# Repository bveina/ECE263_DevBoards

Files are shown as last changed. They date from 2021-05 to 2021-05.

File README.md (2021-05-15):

# ECE 263 Breakout Boards
There are three revisions of the ECE 263 breakout board. each is published in this repository.

each folder contains the Eagle files, a pdf of each schematic, a gerber folder,and two png renders of the board, top and bottom.

## [Version 1 - The White Board](./ECE263_breakout_V1)
## [Version 2 - The Green Board](./ECE263_breakout_V2)
## [Version 3 - The Red Board](./ECE263_breakout_V3)

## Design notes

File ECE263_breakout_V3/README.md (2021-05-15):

# ECE 263 Breakout Board Version 3
This repository is the public repo for the version one board for ECE263 "The Red Board"
It is targeted towards the Atmel Xplained Mini328pb not all features will be available if connected to an Arduino.
this repo contains the original board files, and renders of the Schematic and PCB (top and bottom) hosted here for easy reference.

## Building your own
Version three was designed to be assembed automatically by the ECE department Pick and place machine or assembled by hand (in a pinch). all passives are 0805.

|part| part Number|
|---|---|
|seven segment display |LTC-5723HR|
|RGB LED | ASMB-MTB0-0A3A2|
|Buzzer |	PKMCS0909E4000-R1|
| Button| EVP-BFAC1A000|
| transistors| MMBT2222A |

## Potentiometers
Three potentiometers are connected across the power rail with wipers connected to the Analog to Digital Converter (ADC) pins.
- 328p pins PORT: C0, C1, C2

## Buttons
Three Momentary buttons are hooked up the processor to pull the inputs to ground when pressed.
Pull up resistors are onboard so the internal pull ups of the 328p/328pb don't need be activated.
- 328p pins: PORTE 0,1,2

## Seven Segment Display
A socket is provided for a 4 digit seven segment display with Common Cathodes.

- Digit Enables:
 - PORTB 0,1,2,3
- Anodes (abcdefg.):
 - PORTD 0,1,2,3,4,5,6,7

## RGB led
A SMD Common Anode LED is included on the expansion board.
each Cathode is connected to a PWM capable Pin.
Color Cathodes (BGR):
- PORT B3,B1,D6
Anode:
- PORT C3

## Speaker
A SMD peizo speaker is enabled by bringing PE3 high then can be controlled by toggling PD2.
D2 is also the modulator output on the atmega328pb.

## IO Expansion Connector
3 external connections are provided on PE0,PB0,PE1.
these have external pullups making them useful for a thermistor or external buttons. they are also the processors Input Capture pins

## SPI Connector
A six pin connector is located under the seven segment display to allow the connection of a  [MAX7221 breakout](https://github.com/bveina/Max7221-Driver).
or any SPI device.
pinout:
1. MOSI0
2. MISO0
3. GND
4. VCC
5. SCK0
6. PB2 (SS0)

## I2C:registered: / TWI Expansion
a 4 pin two wire interface is broken out for connection to external devices
1. GND
2. VCC
3. SDA0/PC4
4. SCL0/PC5

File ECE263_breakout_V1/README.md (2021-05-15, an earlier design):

# ECE 263 Breakout Board Version 1
This repository is the public repo for the version one board for ECE160/263 "the White Board"
it contains the original board files, and renders of the Schematic and Pcb (top and bottom) hosted here for easy reference.

This board was originally designed to mate with a standard arduino uno. but will also work with and atmel Xplained mini 328p or pb

## Potentiometers
Three potentiometers are connected across the power rail with wipers connected to the Analog to Digital Converter (ADC) pins.
- Arduino pins: A0, A1, A2
- 328p pins PORT: C0, C1, C2

## Buttons
Three Momentary buttons are hooked up the processor to pull the inputs to ground when pressed.
Pull up resistors are onboard so the internal pull ups of the 328p/328pb don't need be activated.
- Arduino pins: A3, A4, A5
- 328p pins: PORT C3, C4, C5

## Seven Segment Display
A socket is provided for a 4 digit seven segment display with common Cathodes.
Jumpers 3,4,5 must be set to enable either the seven segment display or the RGB led. Only one can be used at a time.

- Digit Enables:
 - Arduino: Digital 8,9,10,11
 - 328p: PORTB 0,1,2,3
- Anodes (abcdefg.):
 - Arduino: Digital 0,1,2,3,4,5,6,7
 - 328p: PORTD 0,1,2,3,4,5,6,7

## RGB led
A 10MM RGB Common Anode LED is included on the expansion board but must be selected by moving jumpers 3,4,5.

Color Cathodes (BGR):
- Arduino: Digital 9,10,11
- 328p: PORTB 1,2,3
Anode:
- Arduino: Digital 12
- 328p: PORTB 4

## Speaker
A speaker is connected to Digital 13/ PORTB5.

The less this annoying buzzer is used, the better.
its constant buzzing is what led to a complete redesign of this board...

## Expansion Connector
3 external connections are provided on portC/analog pins 3,4,5.
these have external pullups making them useful for a thermistor or external buttons.

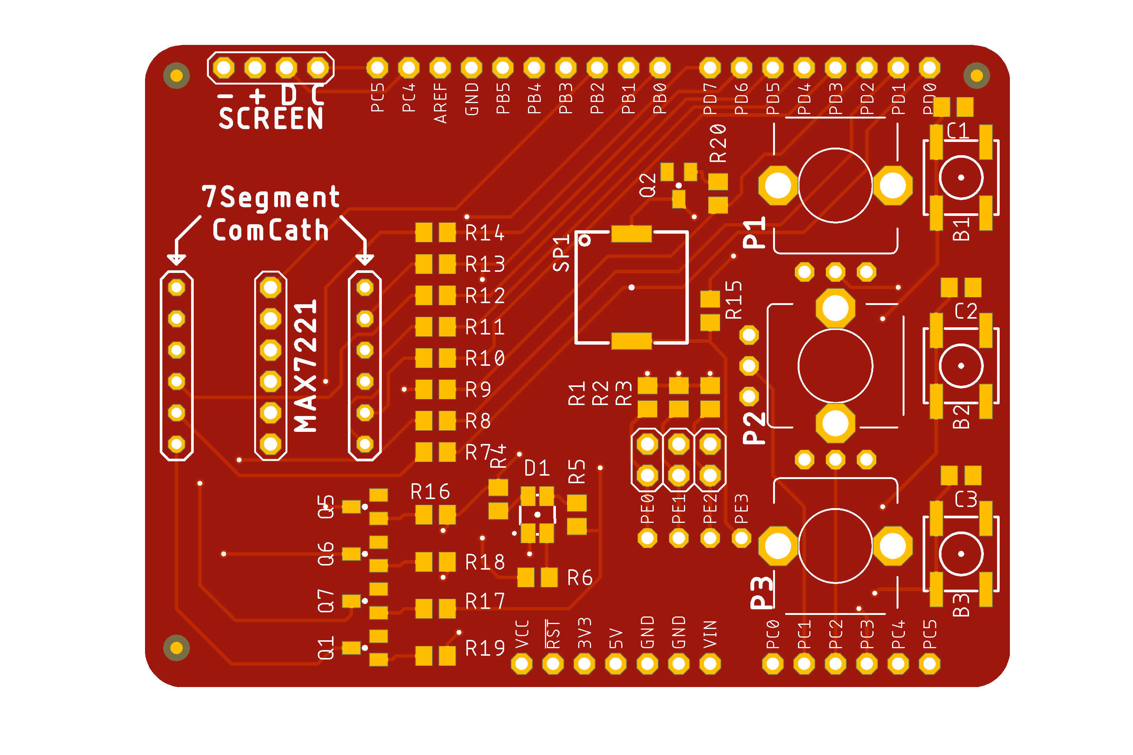
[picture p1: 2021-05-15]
ECE263_breakout_V3/ECE263_V3_PCB_Top.png

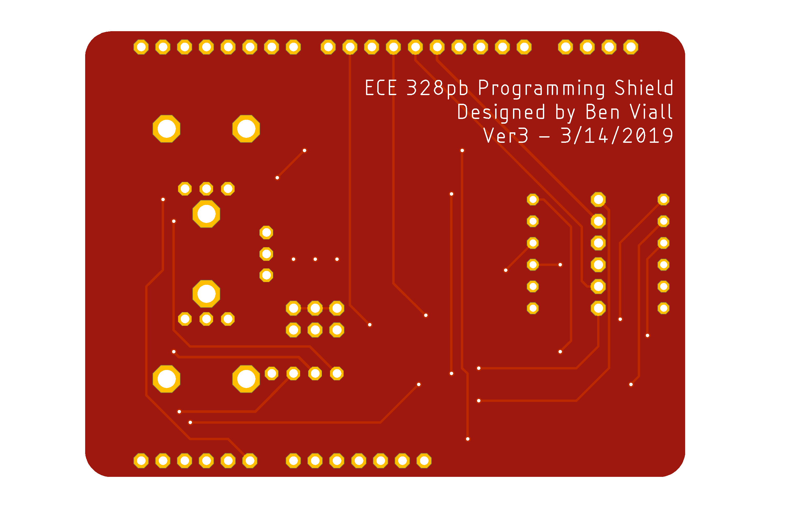
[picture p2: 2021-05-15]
ECE263_breakout_V3/ECE263_V3_Bot.png

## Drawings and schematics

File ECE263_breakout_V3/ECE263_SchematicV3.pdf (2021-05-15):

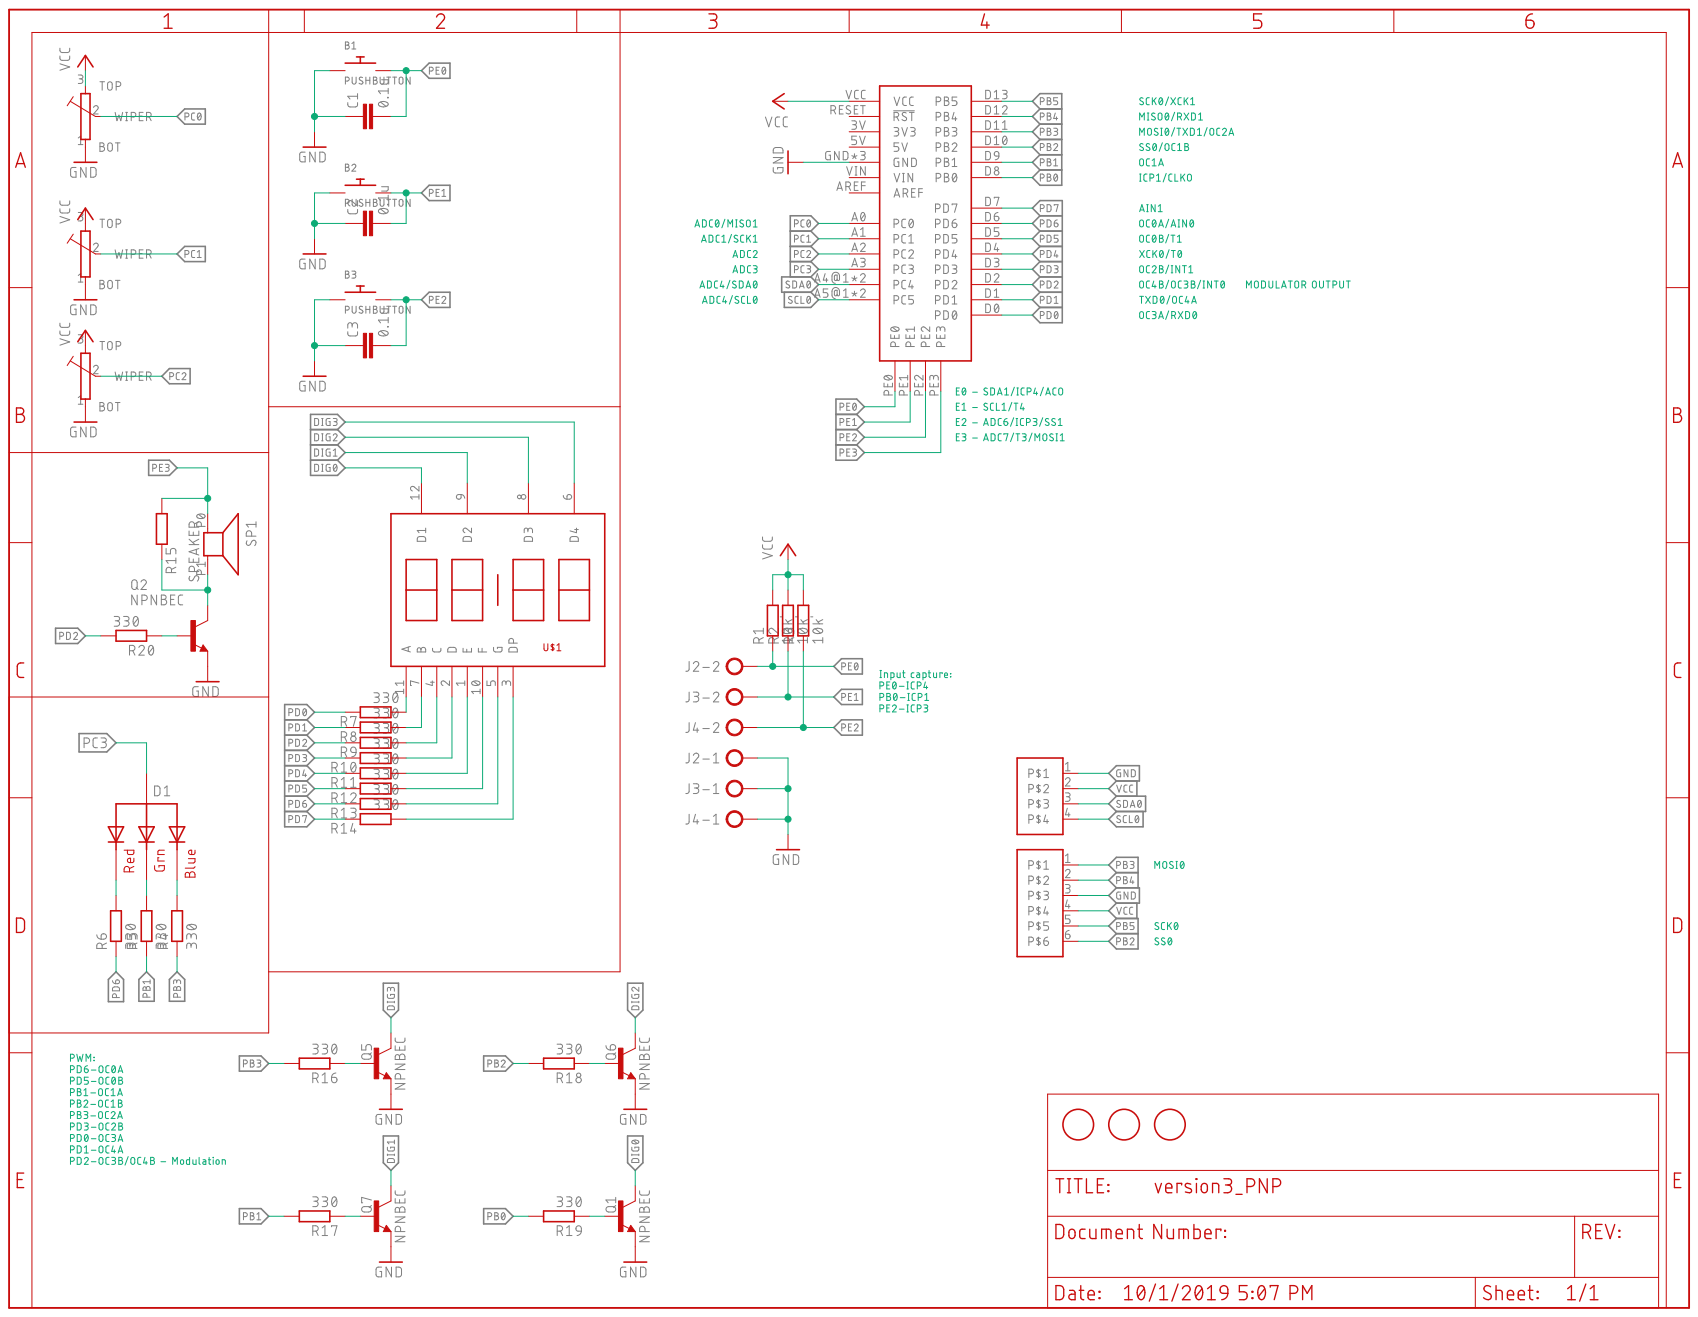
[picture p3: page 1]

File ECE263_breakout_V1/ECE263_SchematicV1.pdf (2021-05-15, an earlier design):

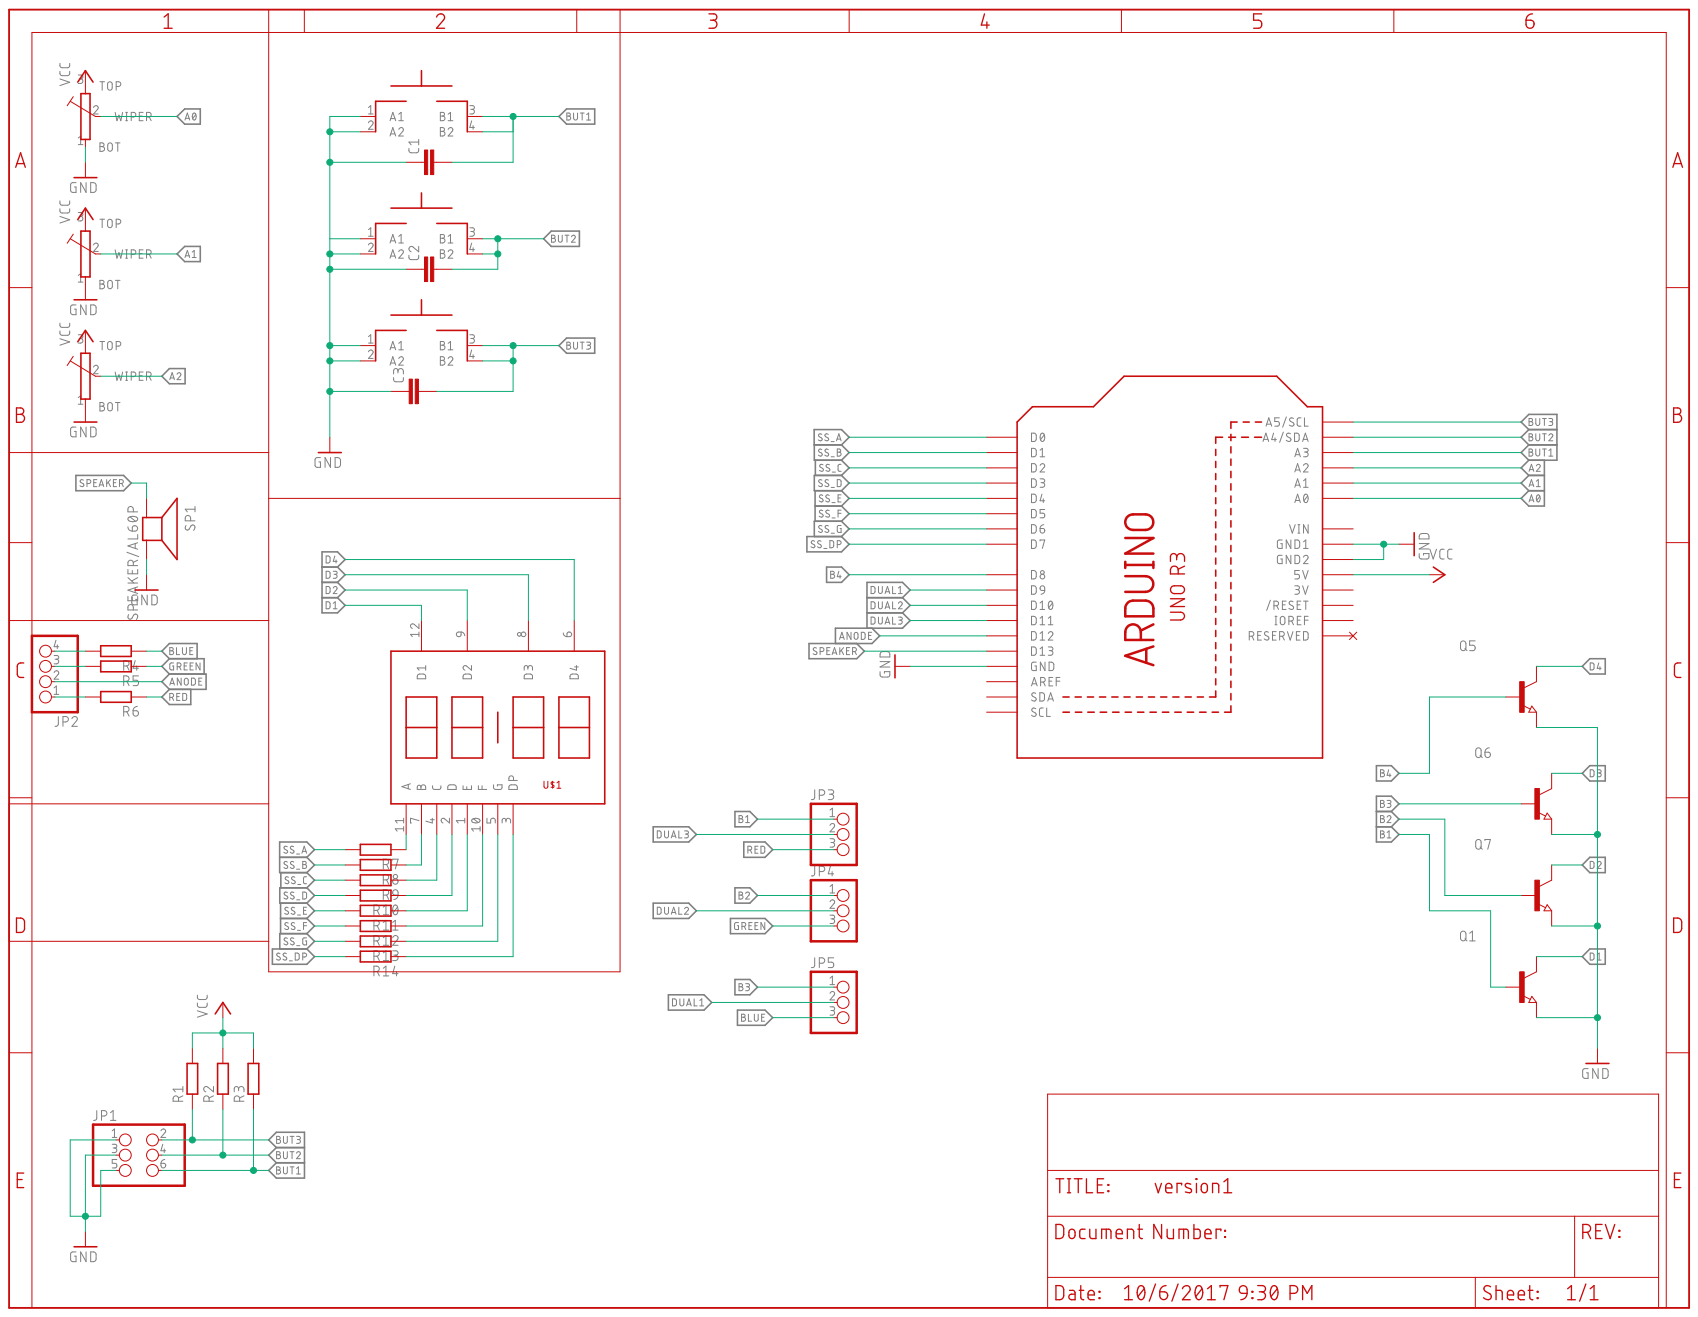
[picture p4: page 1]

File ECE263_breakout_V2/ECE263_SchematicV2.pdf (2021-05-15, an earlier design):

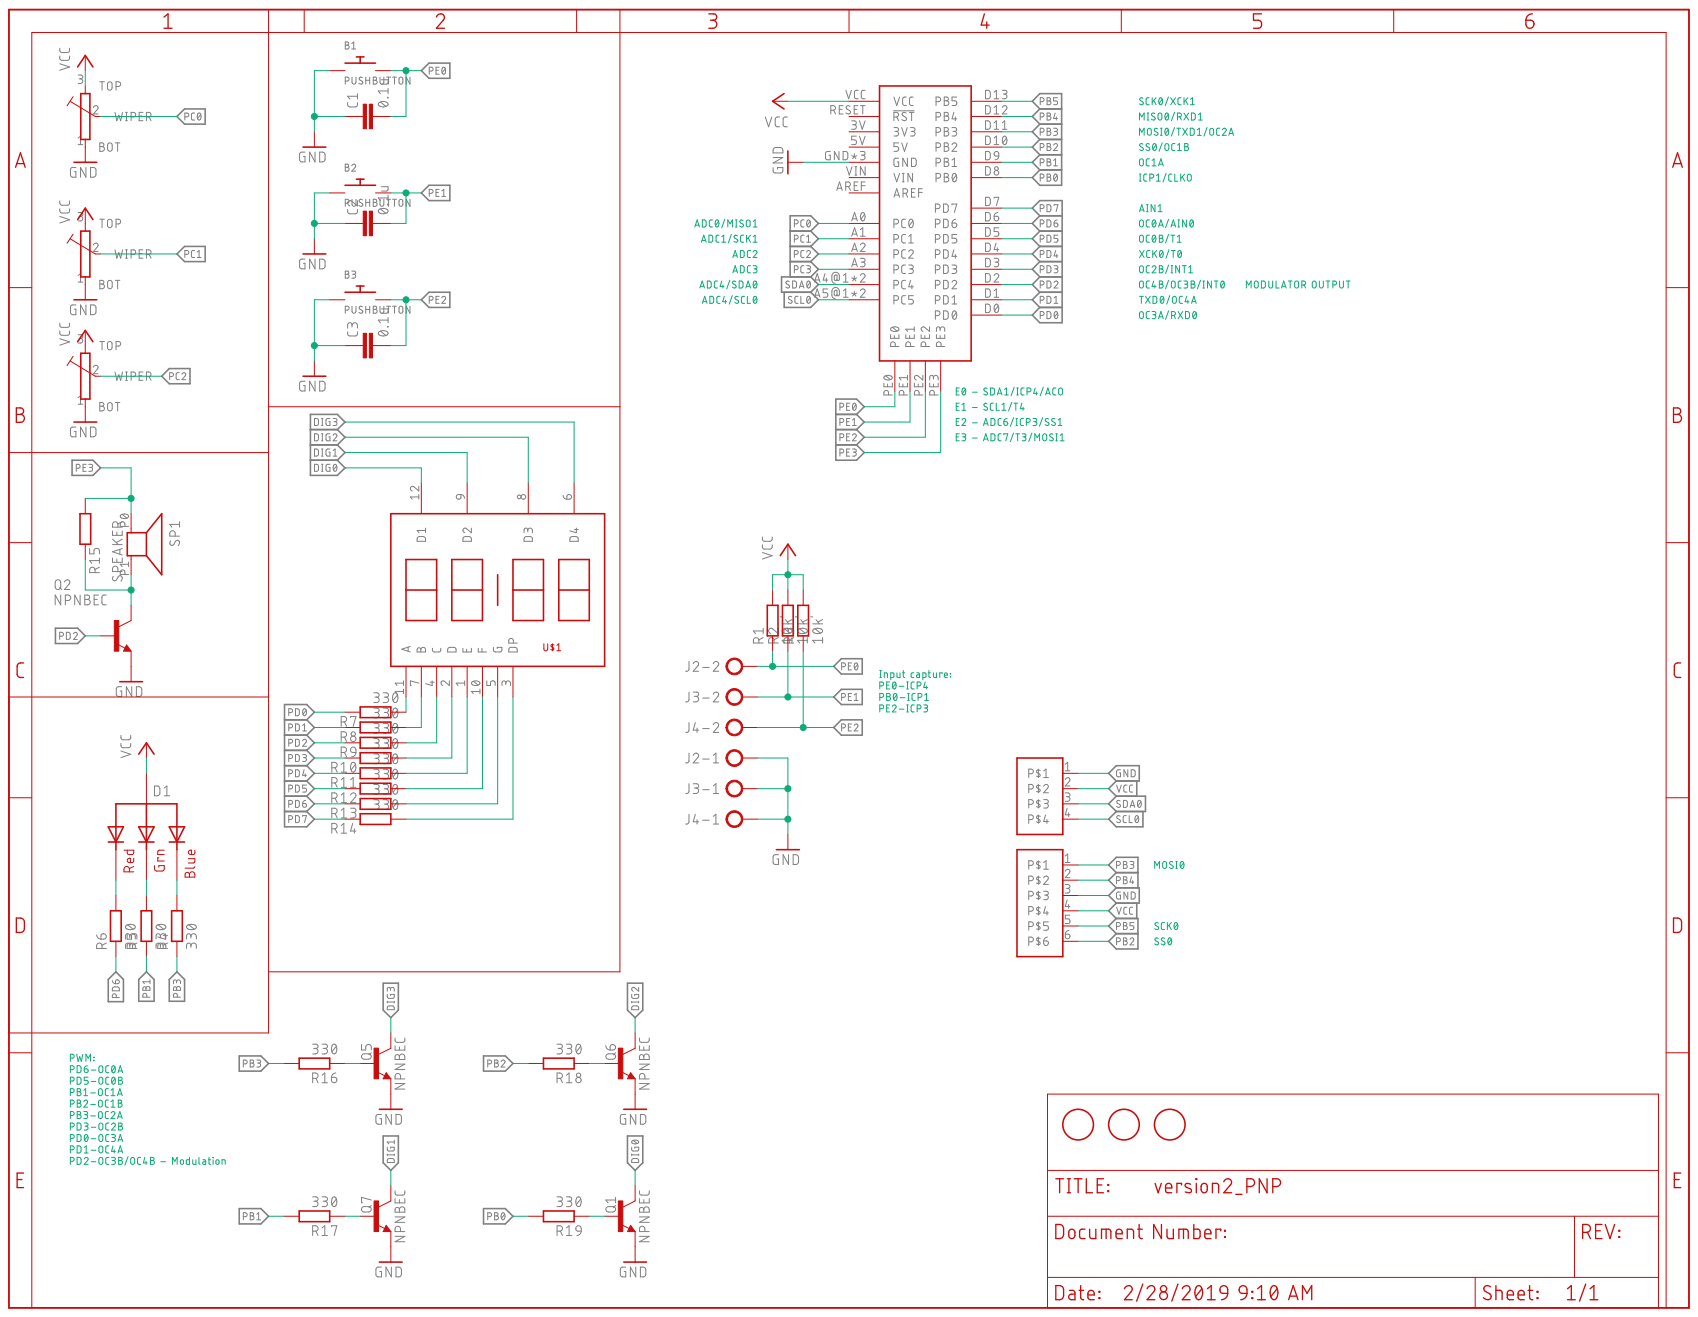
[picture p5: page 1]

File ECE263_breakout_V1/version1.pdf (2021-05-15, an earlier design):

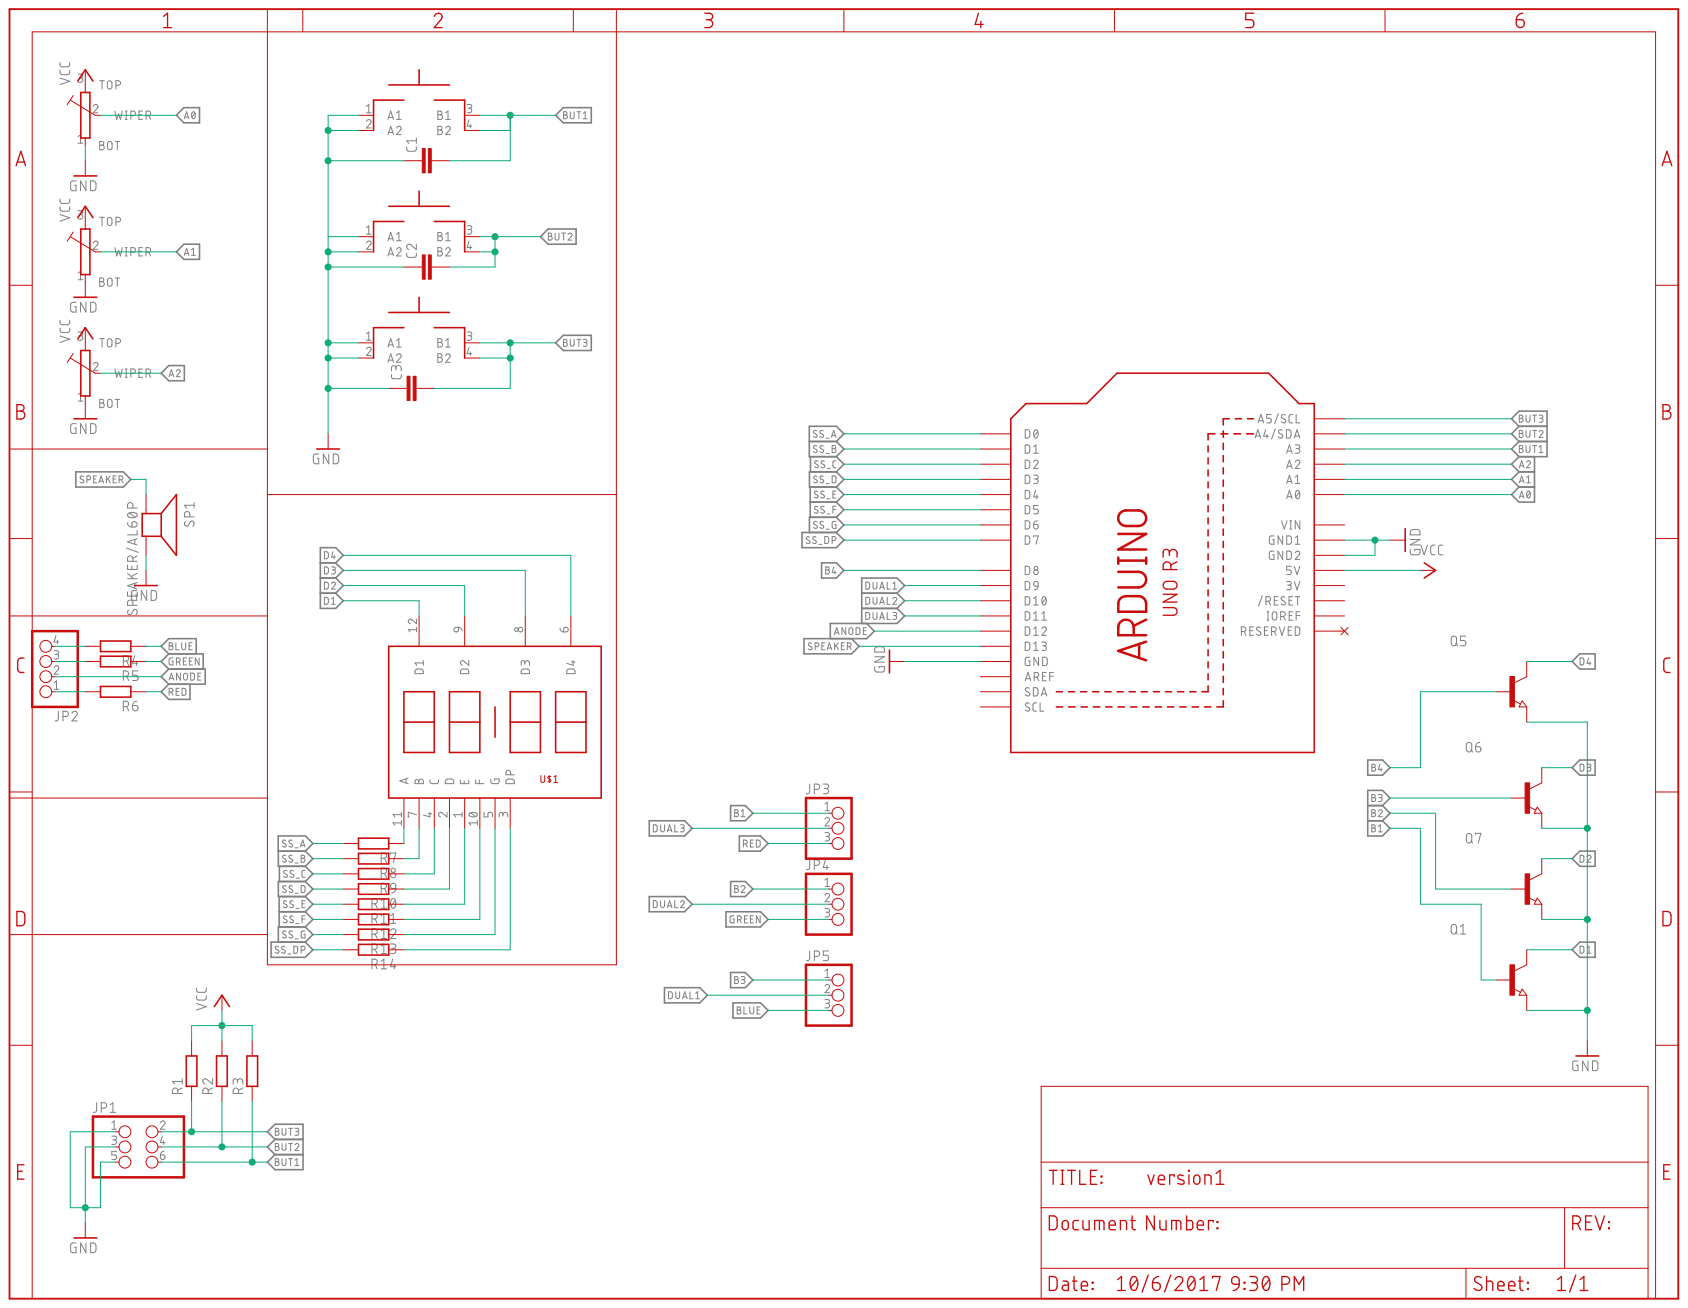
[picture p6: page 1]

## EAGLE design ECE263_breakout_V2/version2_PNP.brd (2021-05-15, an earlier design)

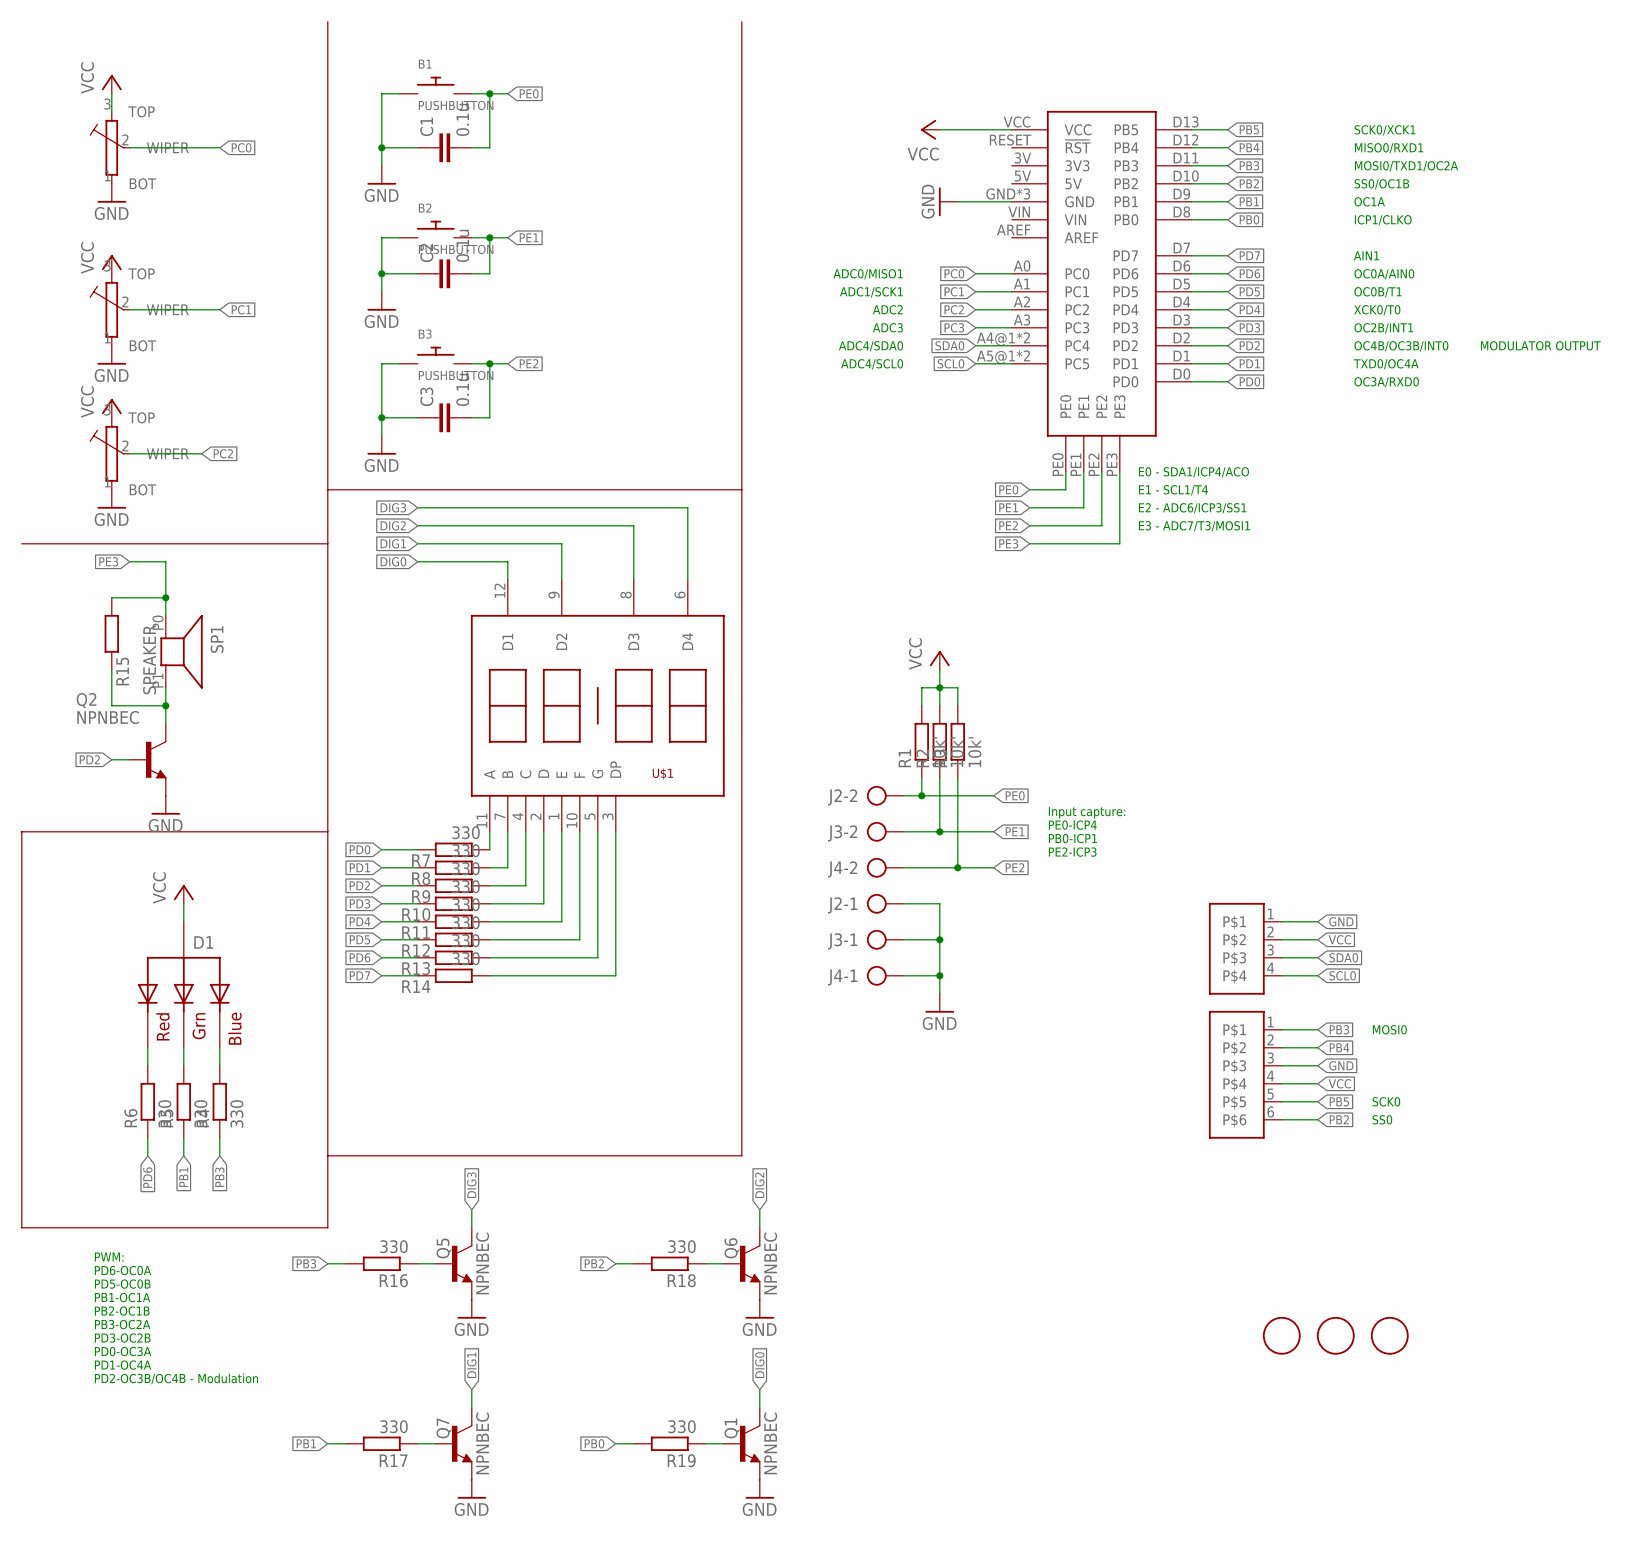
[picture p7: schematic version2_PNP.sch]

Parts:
B1, B2, B3: PUSHBUTTON; BUTTON_EVPBF
C1, C2, C3: 0.1u; C0805
D1: RGB_CA; PLCC-4
J1: M04F; 1X04_FEMALE
J2, J3, J4: 1X02CLEAN; 1X02_CLEAN
Q1, Q2, Q5, Q6, Q7: NPNBEC; SOT23
R1, R2, R3: 10k'; R0805
R4, R5, R6, R7, R8, R9, R10, R11, R12, R13, R14, R16, R17, R18, R19: 330; R0805
R15: R-EU_R0805; R0805
SP1: SPEAKER; PKMCS_SPEAKER
TR1, TR2, TR3: TRIMMTHUMB; RV09
U2: XPLAINEDMINI328PB; XPLAINEDMINI328P
U$1: 4DIG_7SEG_CATHODE; 4DIG_7SEG_CLOCK
U$2: M06F; 1X06_FEMALE
U$3, U$4, U$5: FIDUCIAL; FIDUCIAL_1MM

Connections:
A: R7.1, U$1.11 (A)
B: R8.1, U$1.7 (B)
C: R9.1, U$1.4 (C)
D: R10.1, U$1.2 (D)
DIG0: Q1.3 (C), U$1.12 (D1)
DIG1: Q7.3 (C), U$1.9 (D2)
DIG2: Q6.3 (C), U$1.8 (D3)
DIG3: Q5.3 (C), U$1.6 (D4)
DP: R14.1, U$1.3 (DP)
E: R11.1, U$1.1 (E)
F: R12.1, U$1.10 (F)
G: R13.1, U$1.5 (G)
GND: B1.A1, B1.A2, B2.A1, B2.A2, B3.A1, B3.A2, C1.1, C2.1, C3.1, J1.1, J2.1, J3.1, J4.1, Q1.2 (E), Q2.2 (E), Q5.2 (E), Q6.2 (E), Q7.2 (E), TR1.1 (BOT), TR2.1 (BOT), TR3.1 (BOT), U2.GND, U2.GND1 (GND), U2.GND2 (GND), U$2.3
unnamed: D1.P2 (BLUE), R4.2
unnamed: D1.P3 (GREEN), R5.2
unnamed: D1.P4 (RED), R6.2
unnamed: Q2.3 (C), R15.2, SP1.P1 (2)
unnamed: Q5.1 (B), R16.1
unnamed: Q1.1 (B), R19.1
unnamed: Q6.1 (B), R18.1
unnamed: Q7.1 (B), R17.1
PB0: R19.2, U2.D8 (PB0)
PB1: R5.1, R17.2, U2.D9 (PB1)
PB2: R18.2, U2.D10 (PB2), U$2.6
PB3: R4.1, R16.2, U2.D11 (PB3), U$2.1
PB4: U2.D12 (PB4), U$2.2
PB5: U2.D13 (PB5), U$2.5
PC0: TR1.2 (WIPER), U2.A0 (PC0)
PC1: TR2.2 (WIPER), U2.A1 (PC1)
PC2: TR3.2 (WIPER), U2.A2 (PC2)
PC3: U2.A3 (PC3)
PD0: R7.2, U2.D0
PD1: R8.2, U2.D1
PD2: Q2.1 (B), R9.2, U2.D2
PD3: R10.2, U2.D3
PD4: R11.2, U2.D4
PD5: R12.2, U2.D5
PD6: R6.1, R13.2, U2.D6
PD7: R14.2, U2.D7
PE0: B1.B1, B1.B2, C1.2, J2.2, R1.1, U2.PE0
PE1: B2.B1, B2.B2, C2.2, J3.2, R2.1, U2.PE1
PE2: B3.B1, B3.B2, C3.2, J4.2, R3.1, U2.PE2
PE3: R15.1, SP1.P0 (1), U2.PE3
SCL0: J1.4, U2.A5@1 (PC5), U2.A5@2 (PC5)
SDA0: J1.3, U2.A4@1 (PC4), U2.A4@2 (PC4)
VCC: D1.P1 (VCC), J1.2, R1.2, R2.2, R3.2, TR1.3 (TOP), TR2.3 (TOP), TR3.3 (TOP), U2.VCC, U$2.4

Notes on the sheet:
ICP1/CLKO
OC1A
SS0/OC1B
MOSI0/TXD1/OC2A
MISO0/RXD1
SCK0/XCK1
AIN1
OC0A/AIN0
OC0B/T1
XCK0/T0
OC2B/INT1
TXD0/OC4A
OC3A/RXD0
OC4B/OC3B/INT0
ADC0/MISO1
ADC1/SCK1
ADC2
ADC3
ADC4/SDA0
ADC4/SCL0
E0 - SDA1/ICP4/ACO
E1 - SCL1/T4
E2 - ADC6/ICP3/SS1
E3 - ADC7/T3/MOSI1
MODULATOR OUTPUT
Input capture: PE0-ICP4 PB0-ICP1 PE2-ICP3
PWM: PD6-OC0A PD5-OC0B PB1-OC1A PB2-OC1B PB3-OC2A PD3-OC2B PD0-OC3A PD1-OC4A PD2-OC3B/OC4B - Modulation
MOSI0
SCK0
SS0

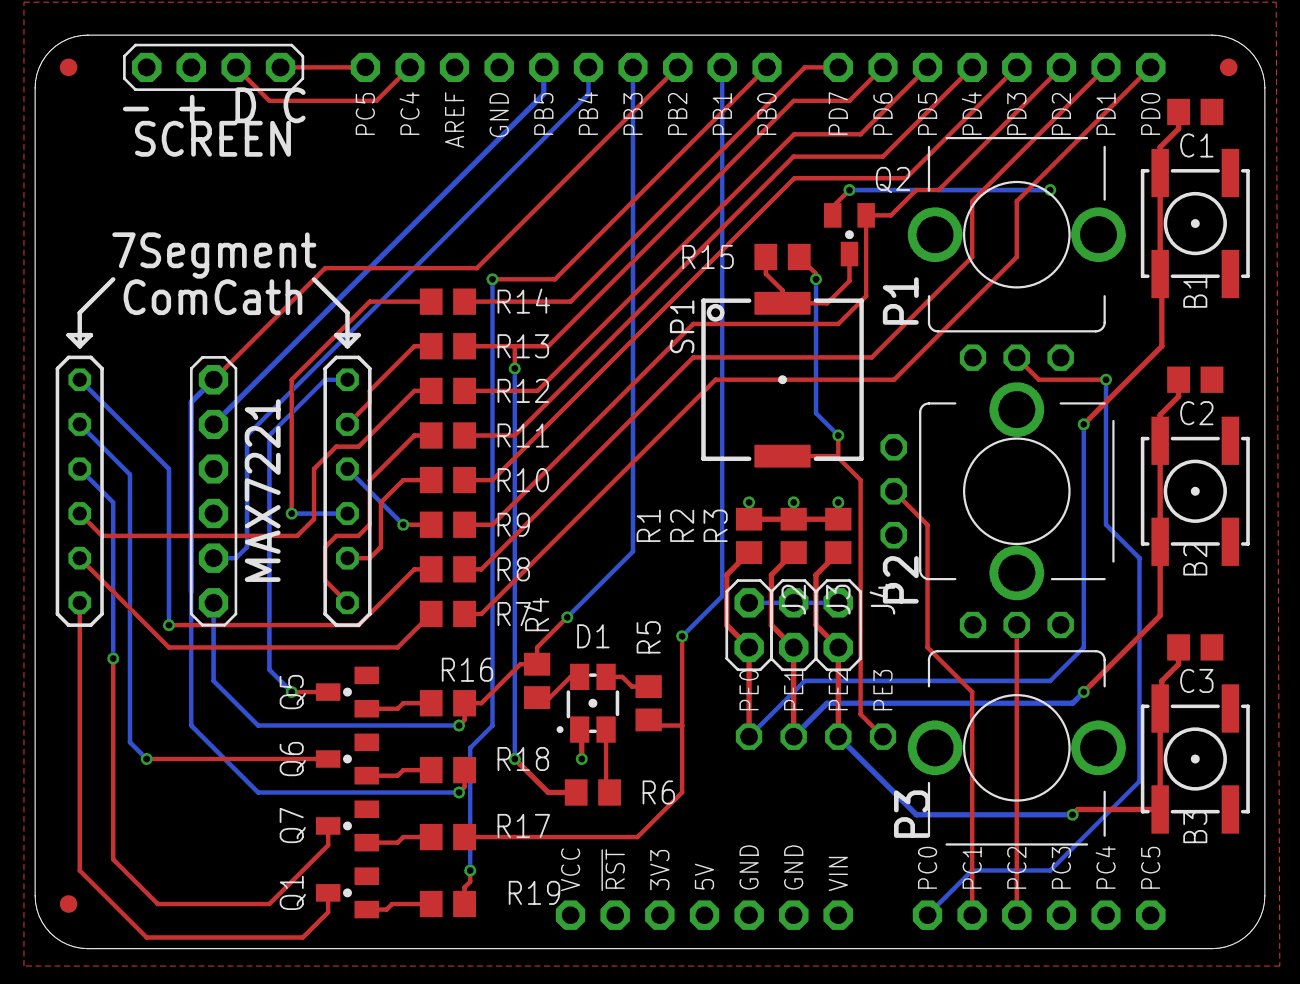
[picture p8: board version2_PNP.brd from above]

Board: 2 copper layers, 70.0 x 52.0 mm, 45 parts (0 on the bottom side), 45 nets.

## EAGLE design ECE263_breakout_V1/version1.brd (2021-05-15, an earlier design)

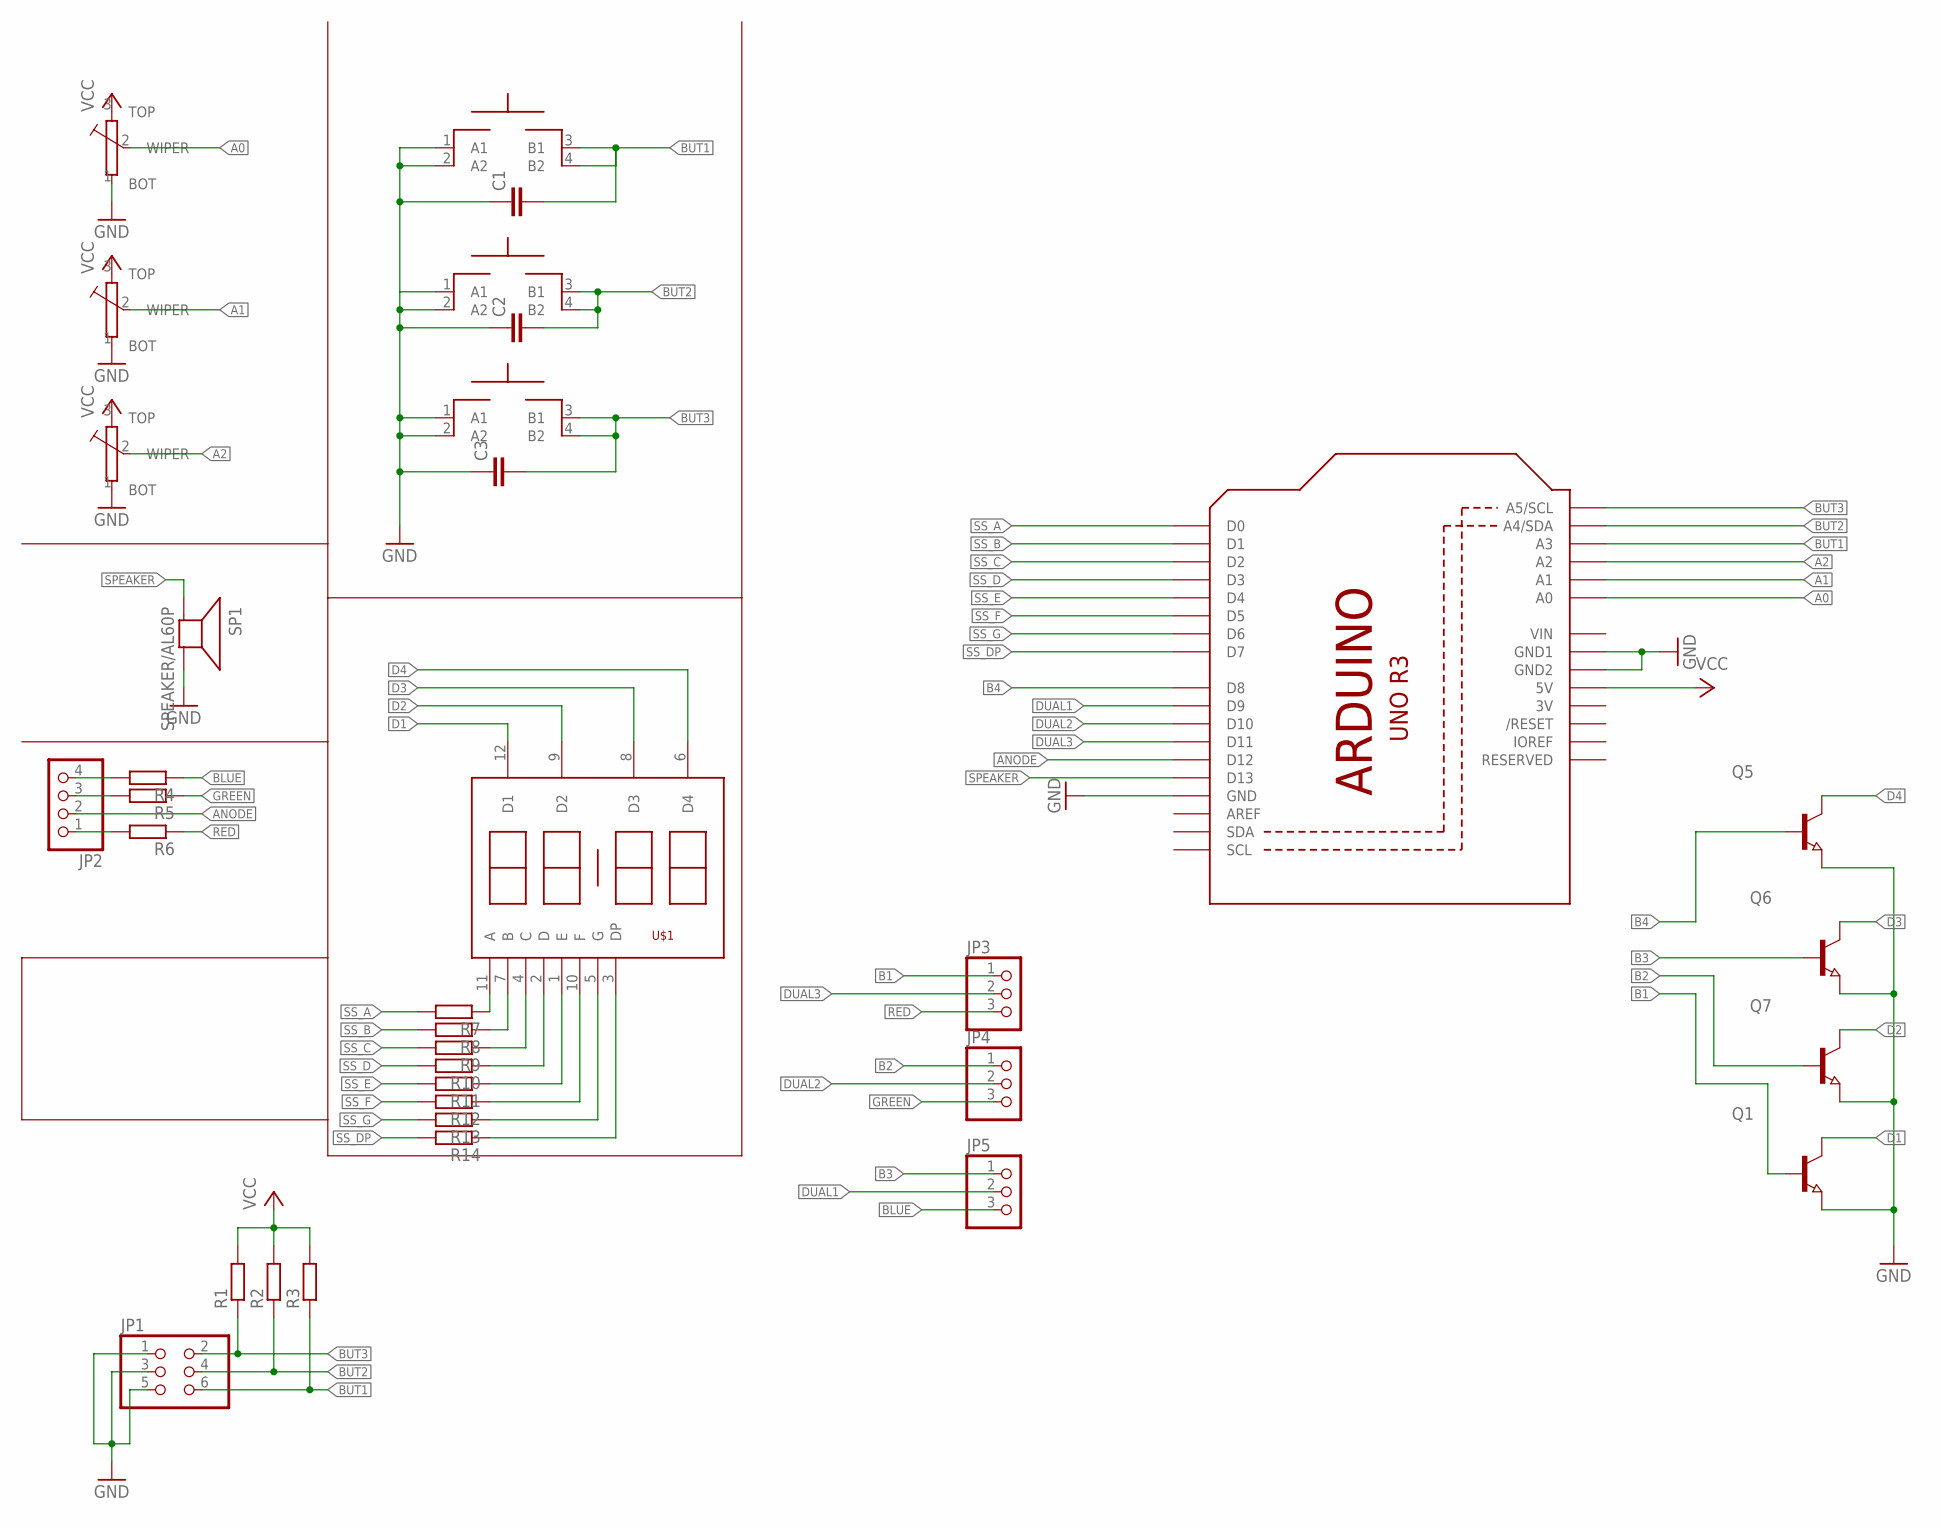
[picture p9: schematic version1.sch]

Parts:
C1, C2, C3: C-EUC0805; C0805
JP1: PINHD-2X3; 2X03
JP2: PINHD-1X4; 1X04
JP3, JP4, JP5: PINHD-1X3; 1X03
Q1, Q5, Q6, Q7: NPN-TRANSISTOR_SOT23; SOT23
R1, R2, R3, R4, R5, R6, R7, R8, R9, R10, R11, R12, R13, R14: R-EU_R0805; R0805
SP1: SPEAKER/AL60P; AL60P
SW1, SW2, SW3: MOMENTARYBUTTON; SPST_NO_SMD
TR1, TR2, TR3: TRIMMTHUMB; RV09
U1: ARDUINOR3-BPLACE
U$1: 4DIG_7SEG_CATHODE; 4DIG_7SEG_CLOCK

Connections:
3V: U1.3V
A0: TR1.2 (WIPER), U1.A0
A1: TR2.2 (WIPER), U1.A1
A2: TR3.2 (WIPER), U1.A2
ANODE: JP2.2, U1.D12
B1: JP3.1, Q1.1 (B)
B2: JP4.1, Q7.1 (B)
B3: JP5.1, Q6.1 (B)
B4: Q5.1 (B), U1.D8
BLUE: JP5.3, R4.1
BUT1: C1.2, JP1.6, R3.1, SW1.3 (B1), SW1.4 (B2), U1.A3
BUT2: C2.2, JP1.4, R2.1, SW2.3 (B1), SW2.4 (B2), U1.A4 (A4/SDA)
BUT3: C3.2, JP1.2, R1.1, SW3.3 (B1), SW3.4 (B2), U1.A5 (A5/SCL)
D1: Q1.3 (C), U$1.12 (D1)
D2: Q7.3 (C), U$1.9 (D2)
D3: Q6.3 (C), U$1.8 (D3)
D4: Q5.3 (C), U$1.6 (D4)
DUAL1: JP5.2, U1.D9
DUAL2: JP4.2, U1.D10
DUAL3: JP3.2, U1.D11
GND: C1.1, C2.1, C3.1, JP1.1, JP1.3, JP1.5, Q1.2 (E), Q5.2 (E), Q6.2 (E), Q7.2 (E), SP1.2 (-), SW1.1 (A1), SW1.2 (A2), SW2.1 (A1), SW2.2 (A2), SW3.1 (A1), SW3.2 (A2), TR1.1 (BOT), TR2.1 (BOT), TR3.1 (BOT), U1.GND, U1.GND1, U1.GND2
GREEN: JP4.3, R5.1
unnamed: JP2.4, R4.2
unnamed: JP2.3, R5.2
unnamed: JP2.1, R6.2
unnamed: R7.1, U$1.11 (A)
unnamed: R8.1, U$1.7 (B)
unnamed: R9.1, U$1.4 (C)
unnamed: R10.1, U$1.2 (D)
unnamed: R11.1, U$1.1 (E)
unnamed: R12.1, U$1.10 (F)
unnamed: R13.1, U$1.5 (G)
unnamed: R14.1, U$1.3 (DP)
RED: JP3.3, R6.1
SPEAKER: SP1.1 (+), U1.D13
SS_A: R7.2, U1.D0
SS_B: R8.2, U1.D1
SS_C: R9.2, U1.D2
SS_D: R10.2, U1.D3
SS_DP: R14.2, U1.D7
SS_E: R11.2, U1.D4
SS_F: R12.2, U1.D5
SS_G: R13.2, U1.D6
VCC: R1.2, R2.2, R3.2, TR1.3 (TOP), TR2.3 (TOP), TR3.3 (TOP), U1.5V
VIN: U1.VIN

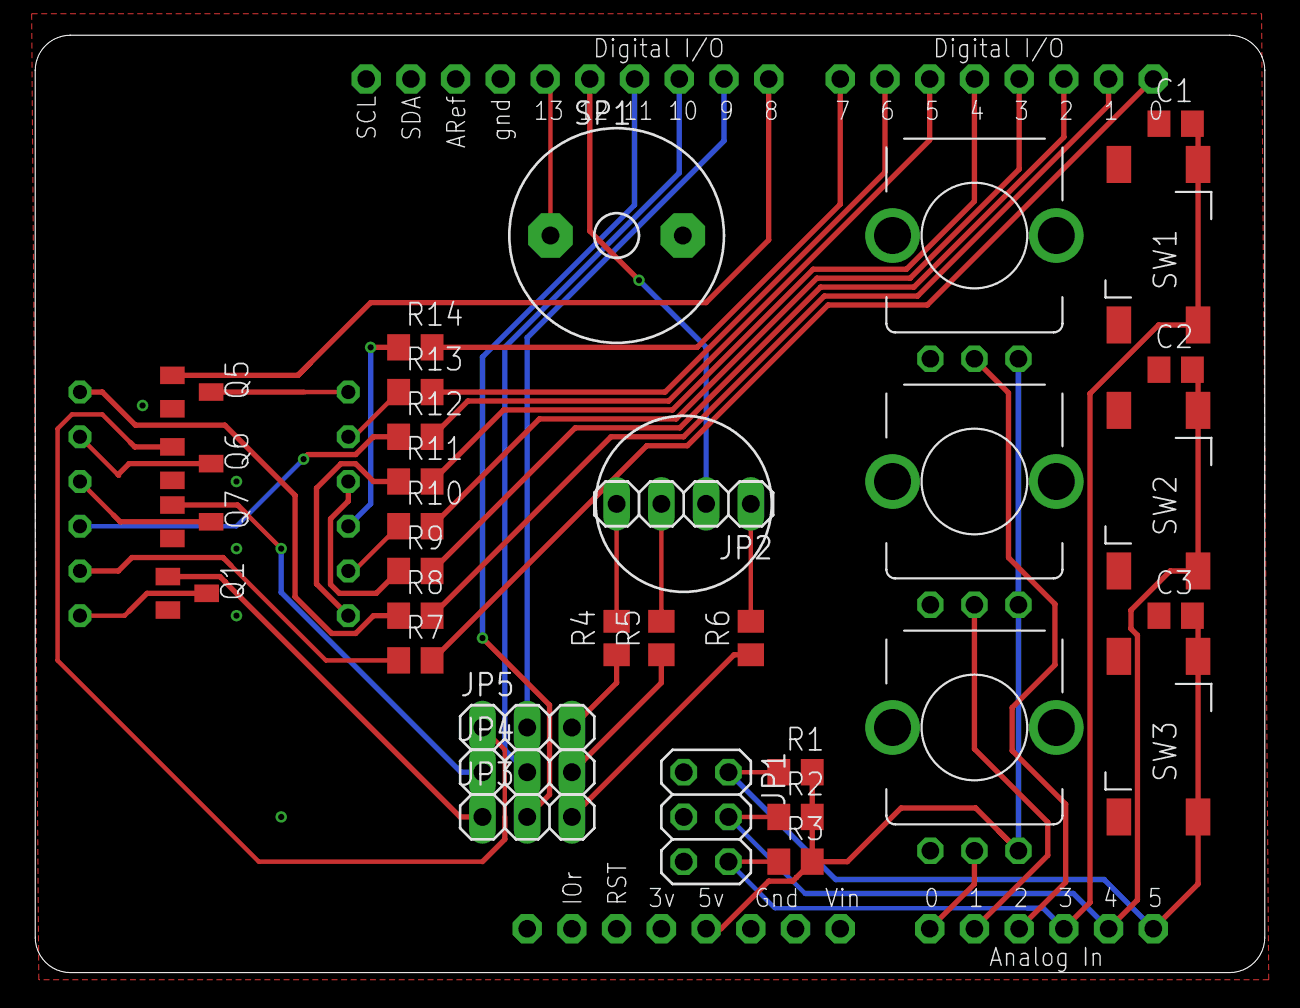
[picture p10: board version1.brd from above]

Board: 2 copper layers, 69.8 x 53.2 mm, 35 parts (0 on the bottom side), 43 nets.
